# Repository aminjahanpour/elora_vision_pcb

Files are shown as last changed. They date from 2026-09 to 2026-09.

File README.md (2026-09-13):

# Elora Vision PCB

KiCad files for image_over_lora project PCB

## Goal
The most important goal for image_over_lora project is to keep the costs low.
So I've made it such that you could simply use already existing boards to set up and work with the porject [just as explained here](https://github.com/aminjahanpour/image_over_lora_android).
For doing that you'd need two boards: a black pill and an a LoRa module.

It could be that a PCB that integerates both of those two modules <b> would cost less</b>.

That is why I've started this project.

## Specs
### General
This is a compact 4-layer PBC powered only via its USB 2.0 connection (Type C plug).
In total, 6 LEDs are included to provide a decent elaboration on both USB and Radio data 
tx/rx processes and possible errors.
A 2-pin SW debug plug is provided for debugging and uploading the firmware.
Also, a USART plug is provided.
To lower the final cost, I used JLCPCB basic parts (rather than extended parts) where I could.
The LCSC part numbers for the parts are included in the BOM.
Use these part numbers to look up the exact components on the JLCPCB website.

### MCU
The board is centered around an STM32F411CEU6 chip.
It provides enough processing power for our Elora Vision firmware.

### LoRa
I chose RX1276 as for the LoRa module because this is perhaps the most common one in North America where I live.
The design targets 915 MHz abiding to the legal frequency bands in Canada.
I went with the IPEX antenna connection because it allows for more flexibility in antenna placement on the UAV.
The radio circuitry is based on the below sources:
- [Semtech reference design](https://www.semtech.com/products/wireless-rf/lora-connect/sx1276)
- [a design by Modtronix](https://modtronix.com/product/inair9b/)

[Also check out my question on StackExchange](https://electronics.stackexchange.com/questions/670470/circuitry-around-sma-for-a-lora-module-pcb-rx1276) regarding the radio circuitry. The given answer is pretty informative.

### Credits

- [A great guide for implementing USB-C in your KiCad projects](https://github.com/jenschr/USB-C-Connectors)
- I highly recommend taking [Phil's Lab PCB design courses](https://www.phils-lab.net/). It helped me a lot.

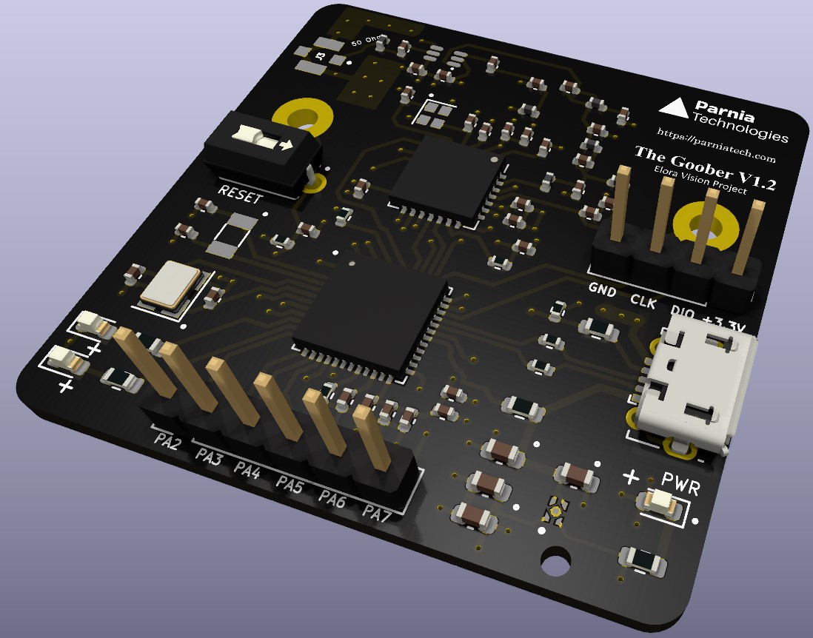
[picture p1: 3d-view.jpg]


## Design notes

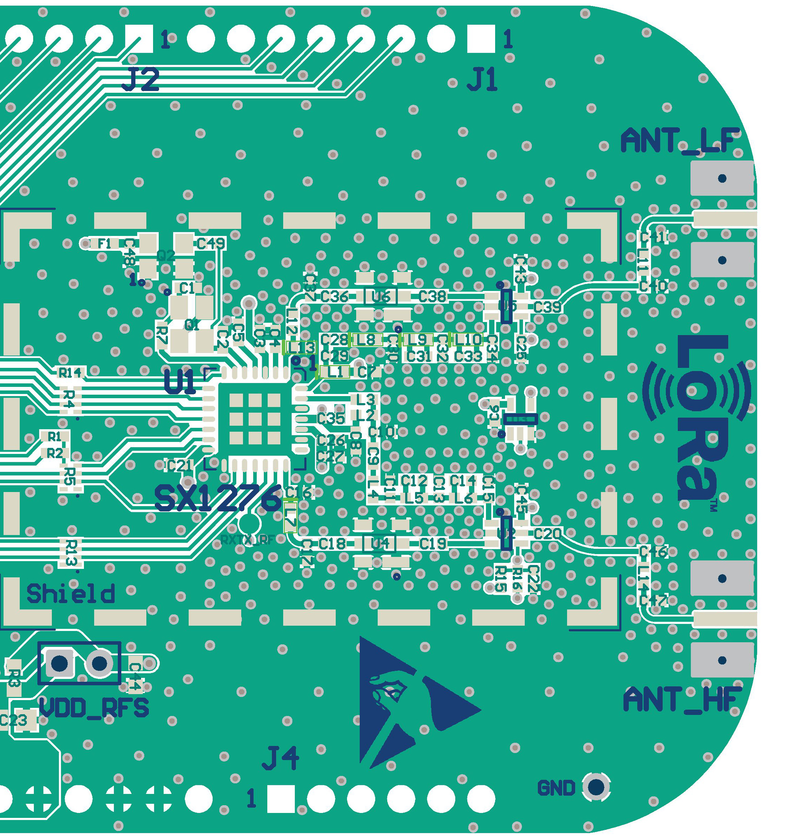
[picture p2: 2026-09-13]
docs/SX1276 Reference Designs/SX1276MB1LAS_e311v02a_prod_folder/SX1276MB1LAS_e311v02a_inductors LQG orientation.jpg

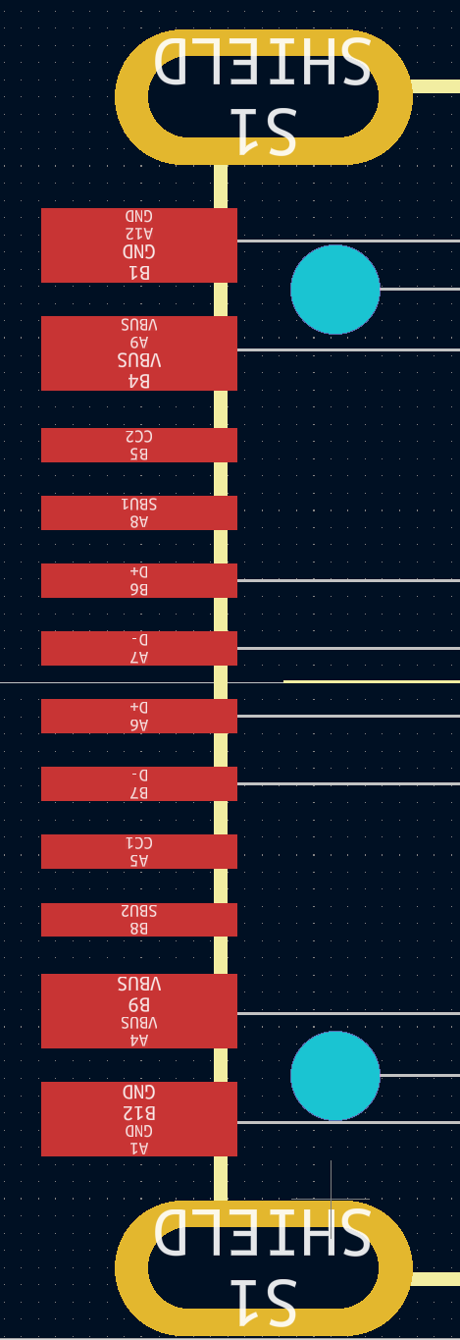
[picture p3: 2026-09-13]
image/usb_c.png

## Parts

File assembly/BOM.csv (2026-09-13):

Comment | Designator | Footprint | LCSC
SW_SPST_SKHLAAA010 | B2 | SKHLAAA010:SKHLAAA010
1uF | C11,C12 | Capacitor_SMD:C_0603_1608Metric
100nF | C14,C15 | Capacitor_SMD:C_0603_1608Metric
47pF | C16,C25,C26,C32,C37 | Capacitor_SMD:C_0402_1005Metric
100nF | C1,C3,C8,C9,C10,C18,C20,C21,C22,C36 | Capacitor_SMD:C_0402_1005Metric
10pF | C19,C38,C40,C43 | Capacitor_SMD:C_0402_1005Metric
10uF | C2 | Capacitor_SMD:C_0402_1005Metric
3.3pF | C24,C30 | Capacitor_SMD:C_0402_1005Metric
8.2pF | C29,C34 | Capacitor_SMD:C_0402_1005Metric
1.5pF | C31 | Capacitor_SMD:C_0402_1005Metric
10nF | C33 | Capacitor_SMD:C_0402_1005Metric
22pF | C35 | Capacitor_SMD:C_0402_1005Metric
2.2pF | C39,C41 | Capacitor_SMD:C_0402_1005Metric
1nF | C4,C23 | Capacitor_SMD:C_0402_1005Metric
2.2uF | C6 | Capacitor_SMD:C_0402_1005Metric
4.7uF | C7 | Capacitor_SMD:C_0402_1005Metric
LED_GREEN_PWR | D1 | LED_SMD:LED_0603_1608Metric
LED_GREEN_1 | D2 | LED_SMD:LED_0603_1608Metric
LED_YELLOW_1 | D3 | LED_SMD:LED_0603_1608Metric
MountingHole_Pad | H3,H4 | MountingHole:MountingHole_2.2mm_M2_Pad
USB_B_Micro | J1 | Connector_USB:USB_Micro-B_Molex-105017-0001
Conn_01x04_Male | J2 | Connector_PinHeader_2.54mm:PinHeader_1x04_P2.54mm_Vertical
IPEX_73412-0114 | J3 | MOLEX_73412-0114
Conn_01x06_Male | J4 | Connector_PinHeader_2.54mm:PinHeader_1x06_P2.54mm_Vertical
0R | L1 | Inductor_SMD:L_0402_1005Metric
10nH Wire | L2 | Inductor_SMD:L_0402_1005Metric
4.7nH Wire | L4 | Inductor_SMD:L_0402_1005Metric
5.6nH Wire | L5 | Inductor_SMD:L_0402_1005Metric
33nH | L6 | Inductor_SMD:L_0402_1005Metric
2.2nH Wire | L7 | Inductor_SMD:L_0402_1005Metric
32MHz | Q1 | Crystal:Crystal_SMD_2016-4Pin_2.0x1.6mm
560 | R1,R8,R9,R10,R13 | Resistor_SMD:R_0603_1608Metric
100k | R15 | Resistor_SMD:R_0402_1005Metric
10K | R2,R3,R6 | Resistor_SMD:R_0402_1005Metric
22 | R4,R5 | Resistor_SMD:R_0402_1005Metric
1k | R7 | Resistor_SMD:R_0402_1005Metric
STM32F411CEU6 | U1 | Package_DFN_QFN:QFN-48-1EP_7x7mm_P0.5mm_EP5.6x5.6mm
AP7340-12FS4-7 | U2 | AP7340D:VREG_AP7340D-25FS4-7
PE4259 | U5 | PE4259:SOT65P215X110-6N
SX1276 | U6 | Package_DFN_QFN:QFN-28-1EP_6x6mm_P0.65mm_EP4.8x4.8mm
12 MHz (C9002) | Y4 | Crystal:Crystal_SMD_3225-4Pin_3.2x2.5mm
32.768 kHz | Y5 | Crystal:Crystal_SMD_3215-2Pin_3.2x1.5mm

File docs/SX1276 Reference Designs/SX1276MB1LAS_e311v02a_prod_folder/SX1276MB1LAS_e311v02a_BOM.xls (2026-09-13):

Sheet: SX1276MB1LAS - BOM
 |  |  | SX1276MB1LAS - BOM |  |  | BOM # V1a
 |  |  |  |  |  | SCH # e311V02a
 |  |  | 2015-11-09 | EMr | Version e311V02a - 915MHz on RF_HF and 433MHz on RF_LF | PCB # e311V02a
RefDes | MPN | Geom | Value | Qty | Description | Manufacturer
IC
U1 | SX1276IMLTRT | TQFN-28 6x6mm | SX1276 | 1 | 137MHz to 1020MHz Low Power Long Range Transceiver | Semtech
U2 | PE4259 | SC-70 | - | 1 | PE4259 - 10MHz to 3GHz SPDT RF Switch | Peregrine Semi
U3 | NC7SZ04P5X | SC-70-5 | - | 1 | NC7SZ04 TinyLogic UHS Inverter | Fairchild Semi
U4 | CRCW06030000Z0EA | 0603 | 0R | 1 | Thick Film Resistor ±5%, 1/10W (No SAW filter populated) | Vishay/Dale
U5 | PE4259 | SC-70 | - | 1 | PE4259 - 10MHz to 3GHz SPDT RF Switch | Peregrine Semi
U6 | CRCW06030000Z0EA | 0603 | 0R | 1 | Thick Film Resistor ±5%, 1/10W (No SAW filter populated) | Vishay/Dale
Resistors
R1 | CRCW04020000Z0ED | 0402 | 0R | 1 | Thick Film Resistor ±5%, 1/16W | Vishay/Dale
R2 | CRCW04020000Z0ED | 0402 | 0R | 1 | Thick Film Resistor ±5%, 1/16W | Vishay/Dale
R3 | CRCW06030000Z0EA | 0603 | 0R | 1 | Thick Film Resistor ±5%, 1/10W | Vishay/Dale
R4 | EXB-N8V101JX | EXB28V | 100R | 1 | SMD Resistor Array Resistors (4x), ±5%, 31mW | Panasonic - ECG
R5 | EXB-N8V101JX | EXB28V | 100R | 1 | SMD Resistor Array Resistors (4x), ±5%, 31mW | Panasonic - ECG
R6 | CRCW06030000Z0EA | 0603 | 0R | 1 | Thick Film Resistor ±5%, 1/10W | Vishay/Dale
R7 | CRCW04020000Z0ED | 0402 | 0R | 1 | Thick Film Resistor ±5%, 1/16W | Vishay/Dale
R10 | CRCW04021K00JNED | 0402 | 1k | 1 | Thick Film Resistor ±5%, 1/16W | Vishay/Dale
R13 | EXB-N8V101JX | EXB28V | 100R | 1 | SMD Resistor Array Resistors (4x), ±5%, 31mW | Panasonic - ECG
R14 | CRCW0402100RJNED | 0402 | 100R | 1 | Thick Film Resistor ±5%, 1/16W | Vishay/Dale
R16 | CRCW0402100RJNED | 0402 | 100R | 1 | Thick Film Resistor ±5%, 1/16W | Vishay/Dale
Capacitors
C1 | GRM1555C1H150JA01D | 0402 | 15pF | 1 | Multilayer ceramic capacitors C0G ±5%, 50V for Rakon Crystal (18pF for NDK) | Murata
C2 | GRM1555C1H150JA01D | 0402 | 15pF | 1 | Multilayer ceramic capacitors C0G ±5%, 50V for Rakon Crystal (18pF for NDK) | Murata
C3 | GRM155R71C104KA88D | 0402 | 100nF | 1 | Multilayer ceramic capacitors X7R ±10%, 16V | Murata
C4 | GRM155R71C104KA88D | 0402 | 100nF | 1 | Multilayer ceramic capacitors X7R ±10%, 16V | Murata
C5 | GRM155R71C104KA88D | 0402 | 100nF | 1 | Multilayer ceramic capacitors X7R ±10%, 16V | Murata
C6 | GRM155R71C104KA88D | 0402 | 100nF | 1 | Multilayer ceramic capacitors X7R ±10%, 16V | Murata
C7 | GRM1555C1H470JZ01D | 0402 | 47pF | 1 | Multilayer ceramic capacitors C0G ±5%, 50V | Murata
C8 | GRM1555C1H470JZ01D | 0402 | 47pF | 1 | Multilayer ceramic capacitors C0G ±5%, 50V | Murata
C9 | GRM1555C1H220JZ01D | 0402 | 22pF | 1 | Multilayer ceramic capacitors C0G ±5%, 50V | Murata
C10 | GRM1555C1H8R2CZ01D | 0402 | 8.2pF | 1 | Multilayer ceramic capacitors C0G ±5%, 50V | Murata
C11 | GRM1555C1H6R8CA01D | 0402 | 6.8pF | 1 | Multilayer ceramic capacitors C0G ±0.25pF, 50V | Murata
C13 | GRM1555C1H3R3CZ01D | 0402 | 3.3pF | 1 | Multilayer ceramic capacitors C0G ±0.25pF, 50V | Murata
C17 | GRM1555C1H3R3CZ01D | 0402 | 3.3pF | 1 | Multilayer ceramic capacitors C0G ±0.25pF, 50V | Murata
C18 | GRM1555C1H470JZ01D | 0402 | 47pF | 1 | Multilayer ceramic capacitors C0G ±5%, 50V | Murata
C19 | GRM1555C1H470JZ01D | 0402 | 47pF | 1 | Multilayer ceramic capacitors C0G ±5%, 50V | Murata
C20 | GRM1555C1H470JZ01D | 0402 | 47pF | 1 | Multilayer ceramic capacitors C0G ±5%, 50V | Murata
C21 | GRM155R71C104KA88D | 0402 | 100nF | 1 | Multilayer ceramic capacitors X7R ±10%, 16V | Murata
C22 | GRM155R71H102JA01D | 0402 | 1nF | 1 | Multilayer ceramic capacitors X7R ±5%, 50V | Murata
C23 | GRM21BR60J226ME39L | 0805 | 22uF | 1 | Multilayer ceramic capacitors X5R ±20%, 6.3V | Murata
C24 | GRM188R61A105KA61D | 0603 | 1uF | 1 | Multilayer ceramic capacitors X5R ±10%, 10V | Murata
C25 | GRM155R71H102JA01D | 0402 | 1nF | 1 | Multilayer ceramic capacitors X7R ±5%, 50V | Murata
C26 | GRM1555C1H470JZ01D | 0402 | 47pF | 1 | Multilayer ceramic capacitors C0G ±5%, 50V | Murata
C27 | GRM155R71C104KA88D | 0402 | 100nF | 1 | Multilayer ceramic capacitors X7R ±10%, 16V | Murata
C28 | LQG15HS15NJ02D | 0402 | 15nH | 1 | Multilayer Inductor ±5% | Murata
C29 | GRM1555C1H4R7CA01D | 0402 | 4.7pF | 1 | Multilayer ceramic capacitors C0G ±0.25pF, 50V | Murata
C30 | GRM1555C1H6R8CA01D | 0402 | 6.8pF | 1 | Multilayer ceramic capacitors C0G ±0.25pF, 50V | Murata
C31 | GRM1555C1H2R7CZ01D | 0402 | 2.7pF | 1 | Multilayer ceramic capacitors C0G ±0.25pF, 50V | Murata
C32 | GRM1555C1H6R8CA01D | 0402 | 6.8pF | 1 | Multilayer ceramic capacitors C0G ±0.25pF, 50V | Murata
C35 | GRM155R71E103KA01D | 0402 | 10nF | 1 | Multilayer ceramic capacitors X7R ±10%, 25V | Murata
C36 | GRM1555C1H470JZ01D | 0402 | 47pF | 1 | Multilayer ceramic capacitors C0G ±5%, 50V | Murata
C38 | GRM1555C1H470JZ01D | 0402 | 47pF | 1 | Multilayer ceramic capacitors C0G ±5%, 50V | Murata
C39 | GRM1555C1H470JZ01D | 0402 | 47pF | 1 | Multilayer ceramic capacitors C0G ±5%, 50V | Murata
C43 | GRM155R71H102JA01D | 0402 | 1nF | 1 | Multilayer ceramic capacitors X7R ±5%, 50V | Murata
C44 | GRM188R61A105KA61D | 0603 | 1uF | 1 | Multilayer ceramic capacitors X5R ±10%, 10V | Murata
C45 | GRM155R71H102JA01D | 0402 | 1nF | 1 | Multilayer ceramic capacitors X7R ±5%, 50V | Murata
C50 | GRM188R61A105KA61D | 0603 | 1uF | 1 | Multilayer ceramic capacitors X5R ±10%, 10V | Murata
Inductors & Ferrites
L1 | LQG15HS82NJ02D | 0402 | 82nH | 1 | Multilayer Inductor ±5% | Murata
L2 | LQW15AN33NJ00D | 0402 | 33nH | 1 | Wirewound Inductor ±5% | Murata
L3 | LQW15AN1N5C00D | 0402 | 1.5nH | 1 | Wirewound Inductor ±0.2nH | Murata
L4 | LQW15AN5N6C10D | 0402 | 5.6nH | 1 | Wirewound Inductor ±0.2nH | Murata
L5 | LQW15AN5N6C10D | 0402 | 5.6nH | 1 | Wirewound Inductor ±0.2nH | Murata
L6 | CRCW04020000Z0ED | 0402 | 0R | 1 | Thick Film Resistor ±5%, 1/16W | Vishay/Dale
L7 | LQG15HS10NJ02D | 0402 | 10nH | 1 | Multilayer Inductor ±5% | Murata
L8 | CRCW04020000Z0ED | 0402 | 0R | 1 | Thick Film Resistor ±5%, 1/16W | Vishay/Dale
L9 | LQG15HS12NJ02D | 0402 | 12nH | 1 | Multilayer Inductor ±5% | Murata
L10 | CRCW04020000Z0ED | 0402 | 0R | 1 | Thick Film Resistor ±5%, 1/16W | Vishay/Dale
L11 | CRCW04020000Z0ED | 0402 | 0R | 1 | Thick Film Resistor ±5%, 1/16W | Vishay/Dale
L12 | GRM1555C1H4R7CZ01D | 0402 | 4.7pF | 1 | Multilayer ceramic capacitors C0G ±0.25pF, 50V | Murata
L13 | LQG15HS18NJ02D | 0402 | 18nH | 1 | Multilayer Inductor ±5% | Murata
L14 | CRCW04020000Z0ED | 0402 | 0R | 1 | Thick Film Resistor ±5%, 1/16W | Vishay/Dale
Crystal (or other referenced vendors)
Q1 | FTR5092-A2 | QESM07 3.2x2.5mm | 32.000MHz | 1 | Crystal unit Rakon; Tol. ±10ppm, Cload=10pF, G-Senstivity=2ppb/G max (populated) | Rakon
or | FTR5123-A0 | QESM09 2.0x1.6mm | 32.000MHz | - | Crystal unit Rakon; Tol. ±10ppm, Cload=10pF, G-Senstivity=2ppb/G max (recommended for new design) | Rakon
Q1 | EXS00A-CS00131 | NX2520SA 2.5x2.0mm | 32.000MHz | - | Crystal unit NDK; Tol. ±10ppm, Cload=10pF, G-Senstivity=2ppb/G max | NDK
or | EXS00A-CS06465 | NX2016SA 2.0x1.6mm | 32.000MHz | - | Crystal unit NDK; Tol. ±10ppm, Cload=10pF, G-Senstivity=2ppb/G max (recommended for new design) | NDK
Q1 | S0197-X-002-3 | QESM07 3.2x2.5mm | 32.000MHz | - | Crystal unit Taitien; Tol. ±10ppm, Cload=10pF, G-Senstivity=2ppb/G max | Taitien
Connectors and others (or P/N equivalent)
ANT_HF | 142-0711-821 | SMA End Launch | 50 Ohms | 1 | SMA End launch jack receptacle for PCB mount | Emerson Network Power
ANT_LF | 142-0711-821 | SMA End Launch | 50 Ohms | 1 | SMA End launch jack receptacle for PCB mount | Emerson Network Power
J1 | 68000-108HLF | Header 1x8 | 8 pins | 1 | 8 Pins - Through hole single row male connector, Bottom side | FCI
J2 | 68000-110HLF | Header 1x10 | 10 pins | 1 | 10 Pins - Through hole single row male connector, Bottom side | FCI
J3 | 68000-108HLF | Header 1x8 | 8 pins | 1 | 8 Pins - Through hole single row male connector, Bottom side | FCI
J4 | 68000-106HLF | Header 1x6 | 6 pins | 1 | 6 Pins - Through hole single row male connector, Bottom side | FCI
Additional or optional components
- | BMIS-205-F | Shield | - | 0 | Standard Surface Mount Shield in two parts with BMIS-205-C cover | Laird Technologies

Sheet: Release
 |  | SX1276MB1LAS - BOM |  |  |  | BOM # V1a
 |  |  |  |  |  | SCH # e311V02a
 |  | 2015-11-09 | EMr | Version e311V02a |  | PCB # e311V02a
Release histroy
Version | Change notes |  |  |  | By
pcb_e311V02a | BOM for SX1276MB1LAS V1a |  |  |  | EMr
 | Added Pull-up/down resistors on RXTX_EXT signal |  |  |  | EMr
 | Modified BOM to have the correct ouput power +17dBm @915MHz and Harmonics |  |  |  | EMr
 | L3, C11 and removed C12 |  |  |  | EMr
 | Modified BOM to have the correct ouput power +14dBm @433MHz |  |  |  | EMr
 | Modified value for references: L1, C28, C29, L8, C30, C32, L10 & C34=NC
 | Modified value for RxTX control on R10=1k; R16=100R |  |  |  | EMr
 | Added two new ref for 32.0MHz crystal |  |  |  | EMr

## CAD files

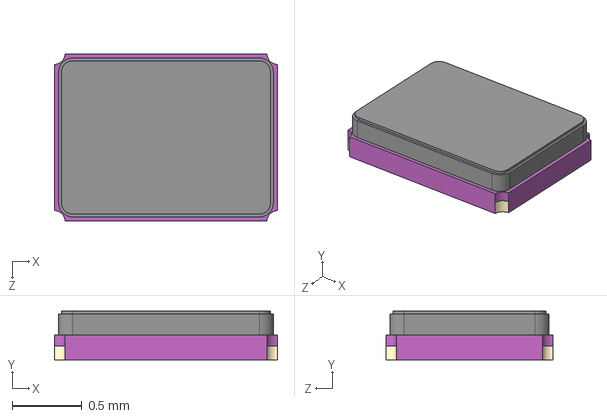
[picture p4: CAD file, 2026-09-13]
added_symbols/NX1612SA-32.000MHZ-CHP-CIS-3/NX1612SA-32.000MHZ-CHP-CIS-3.step
1.60 x 0.35 x 1.20 mm

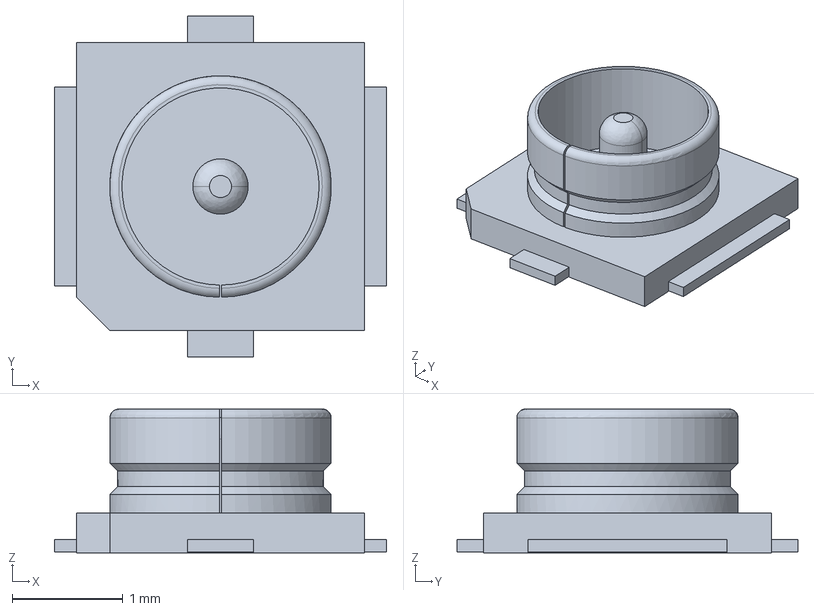
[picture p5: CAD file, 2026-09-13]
added_symbols/ipex_molex_73412-0114/1676492.stp
3.00 x 3.08 x 1.30 mm

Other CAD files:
added_symbols/ipex_molex_73412-0114/73412-0114.step

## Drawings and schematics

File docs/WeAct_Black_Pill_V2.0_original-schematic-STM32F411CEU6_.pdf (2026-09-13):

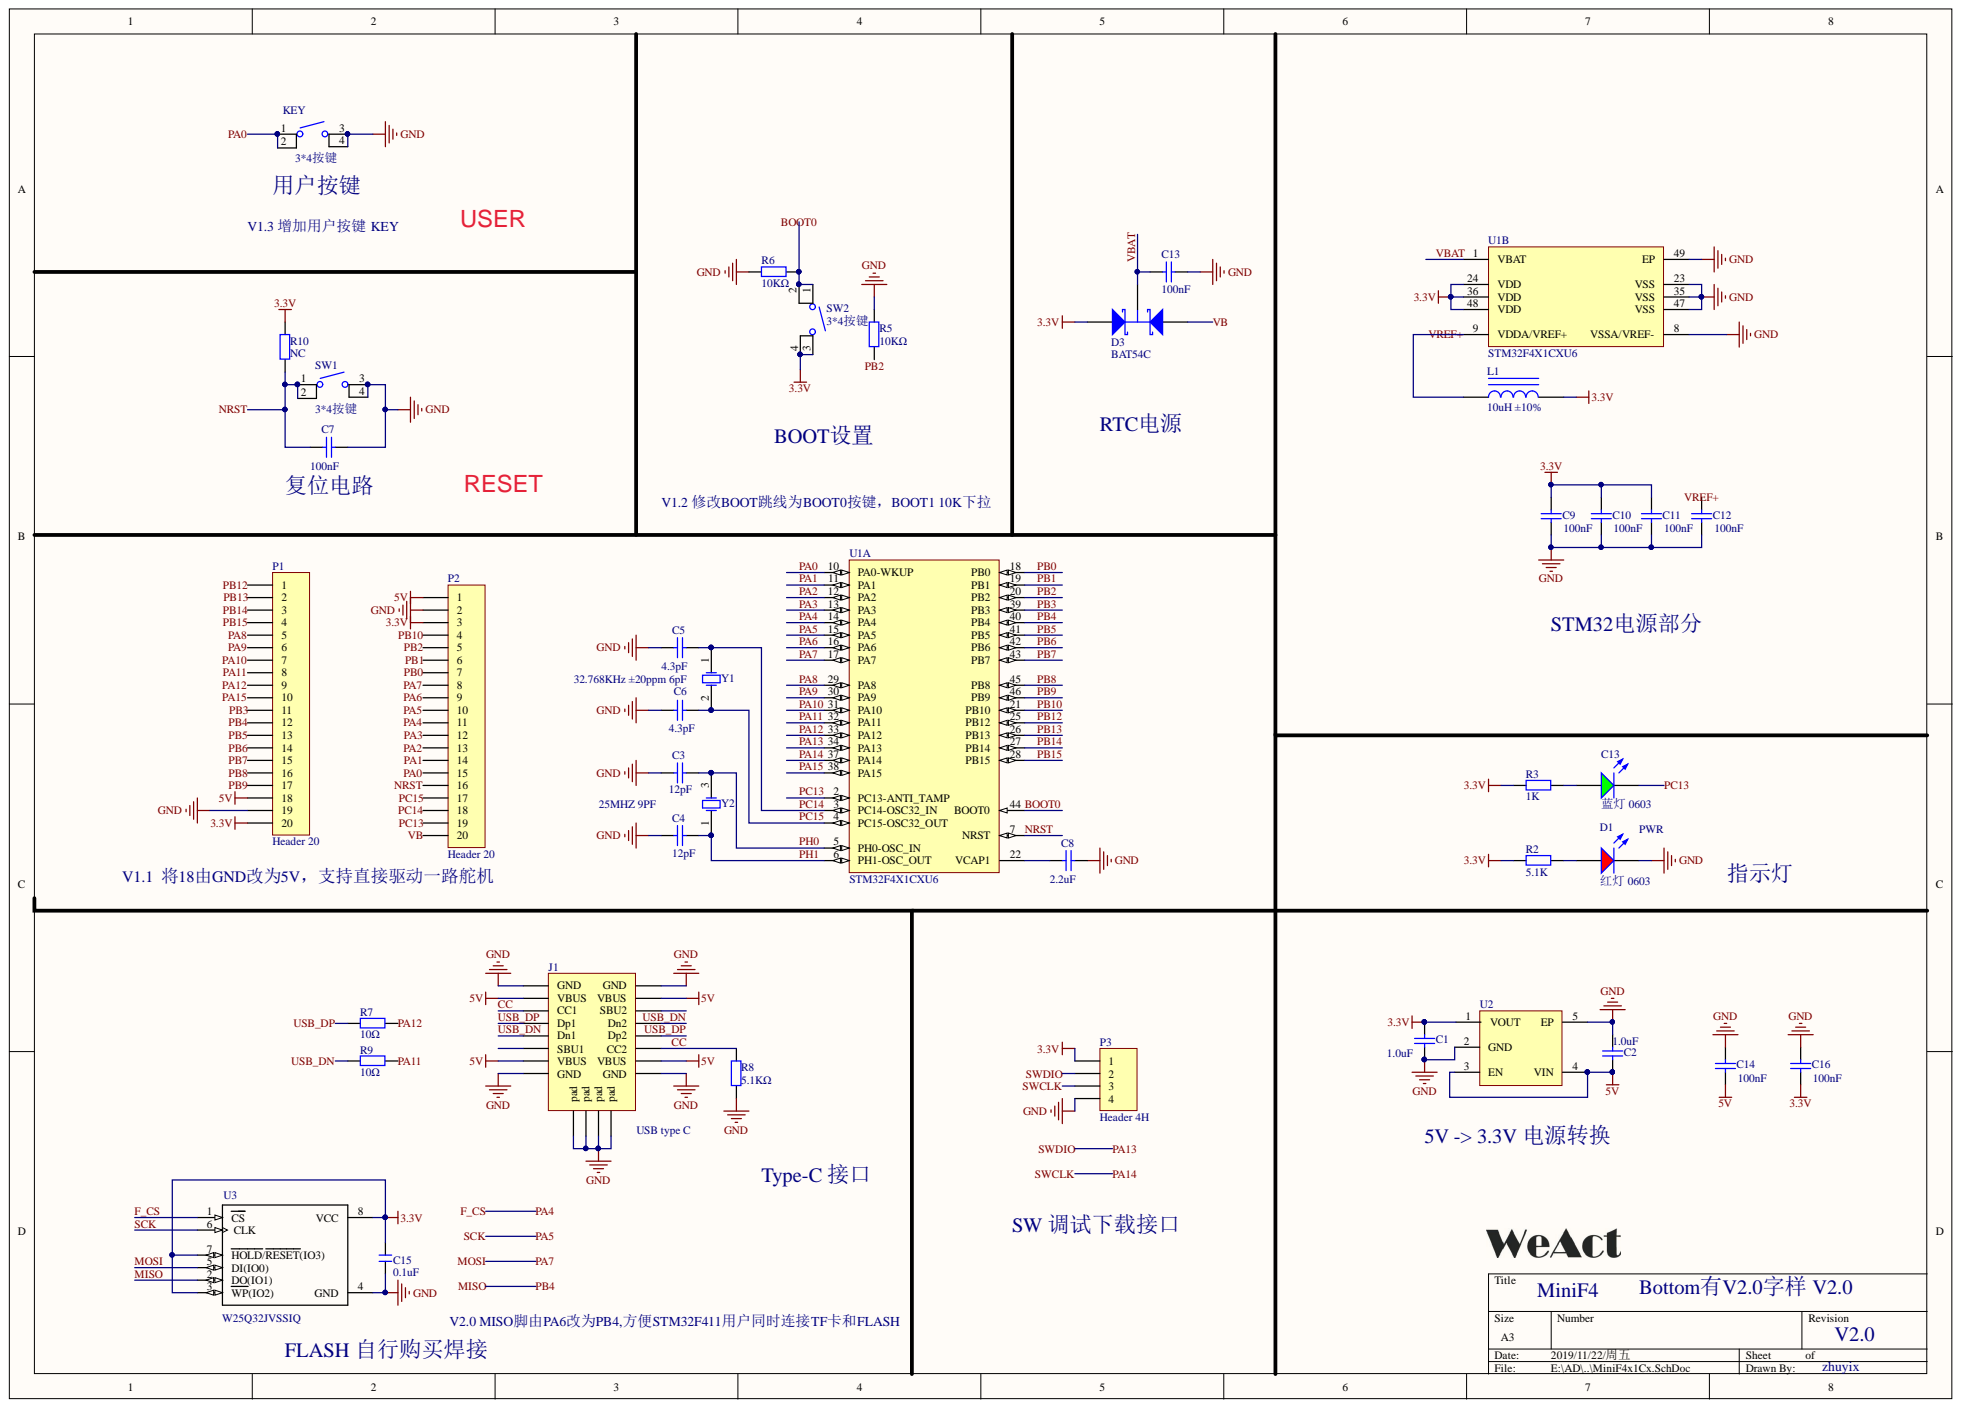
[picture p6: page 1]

PH0-OSC_IN 5

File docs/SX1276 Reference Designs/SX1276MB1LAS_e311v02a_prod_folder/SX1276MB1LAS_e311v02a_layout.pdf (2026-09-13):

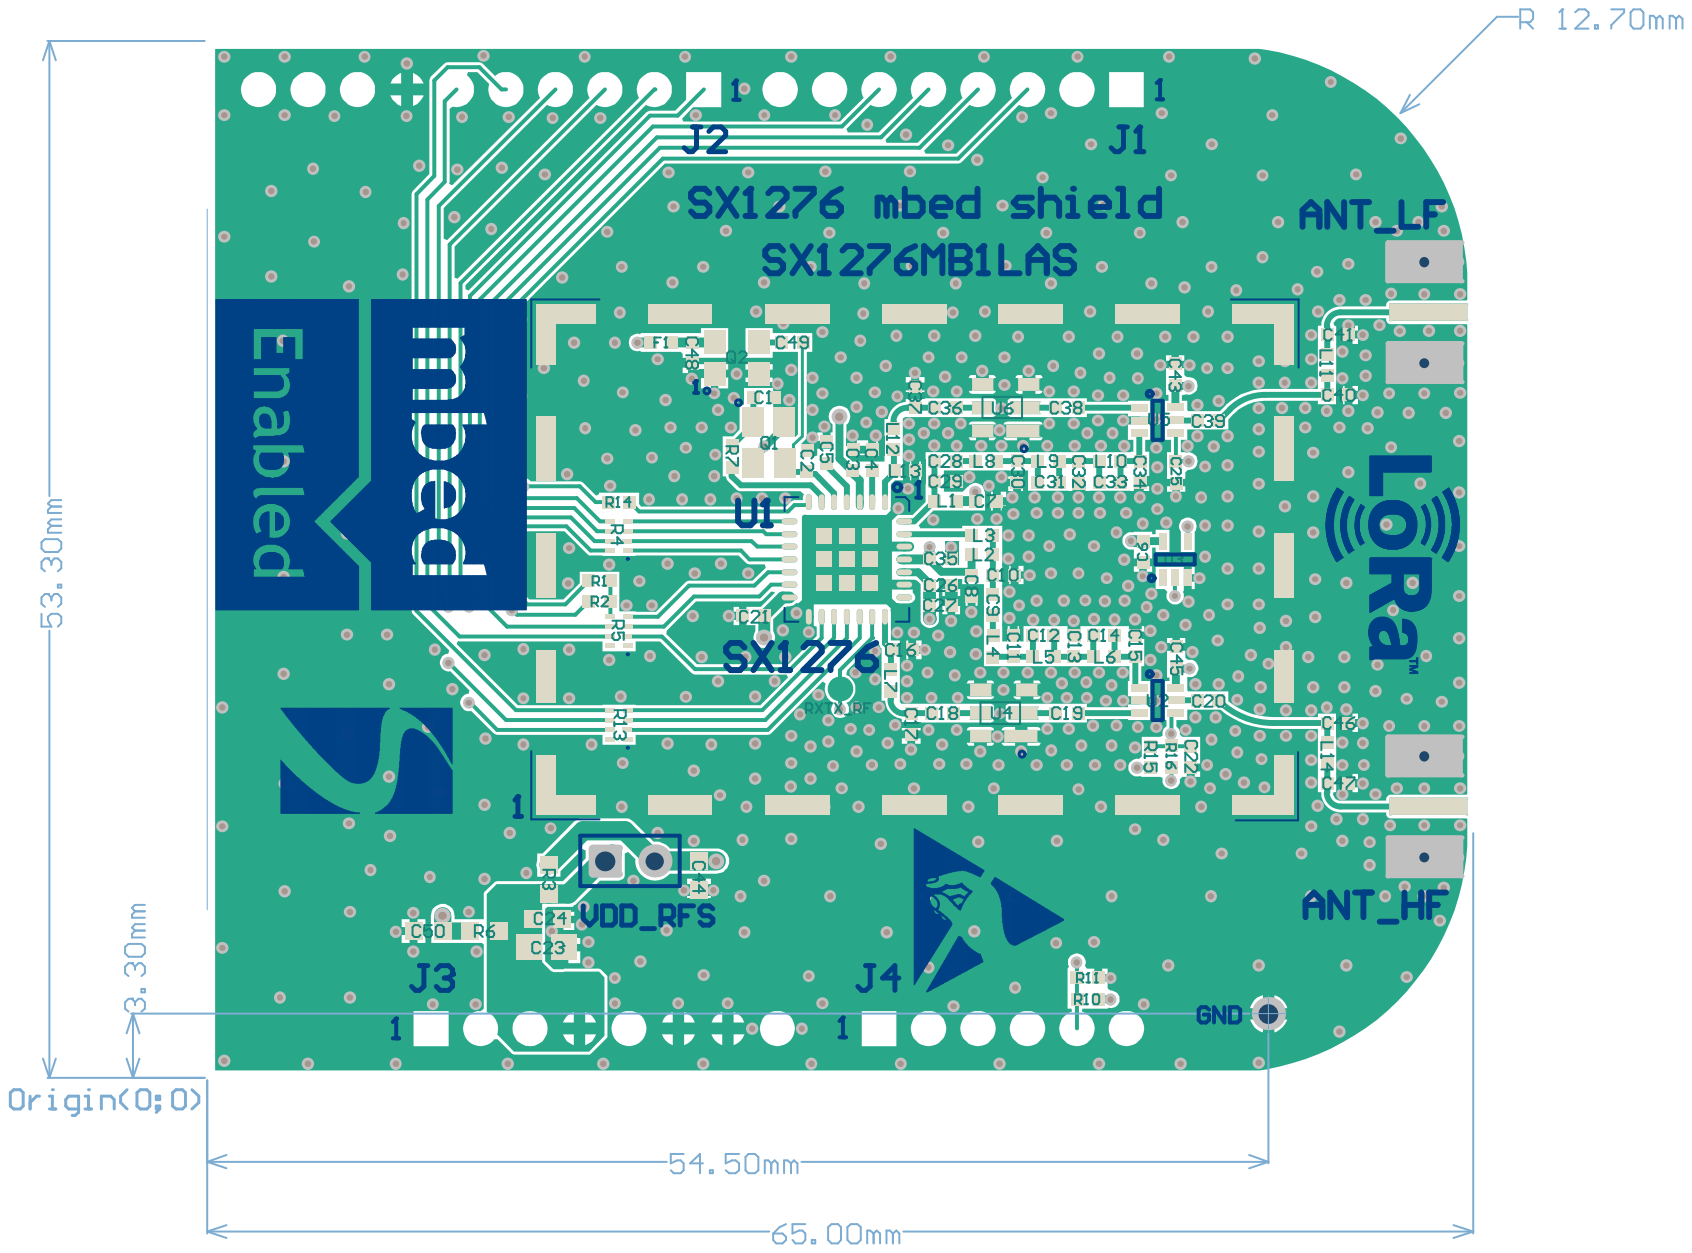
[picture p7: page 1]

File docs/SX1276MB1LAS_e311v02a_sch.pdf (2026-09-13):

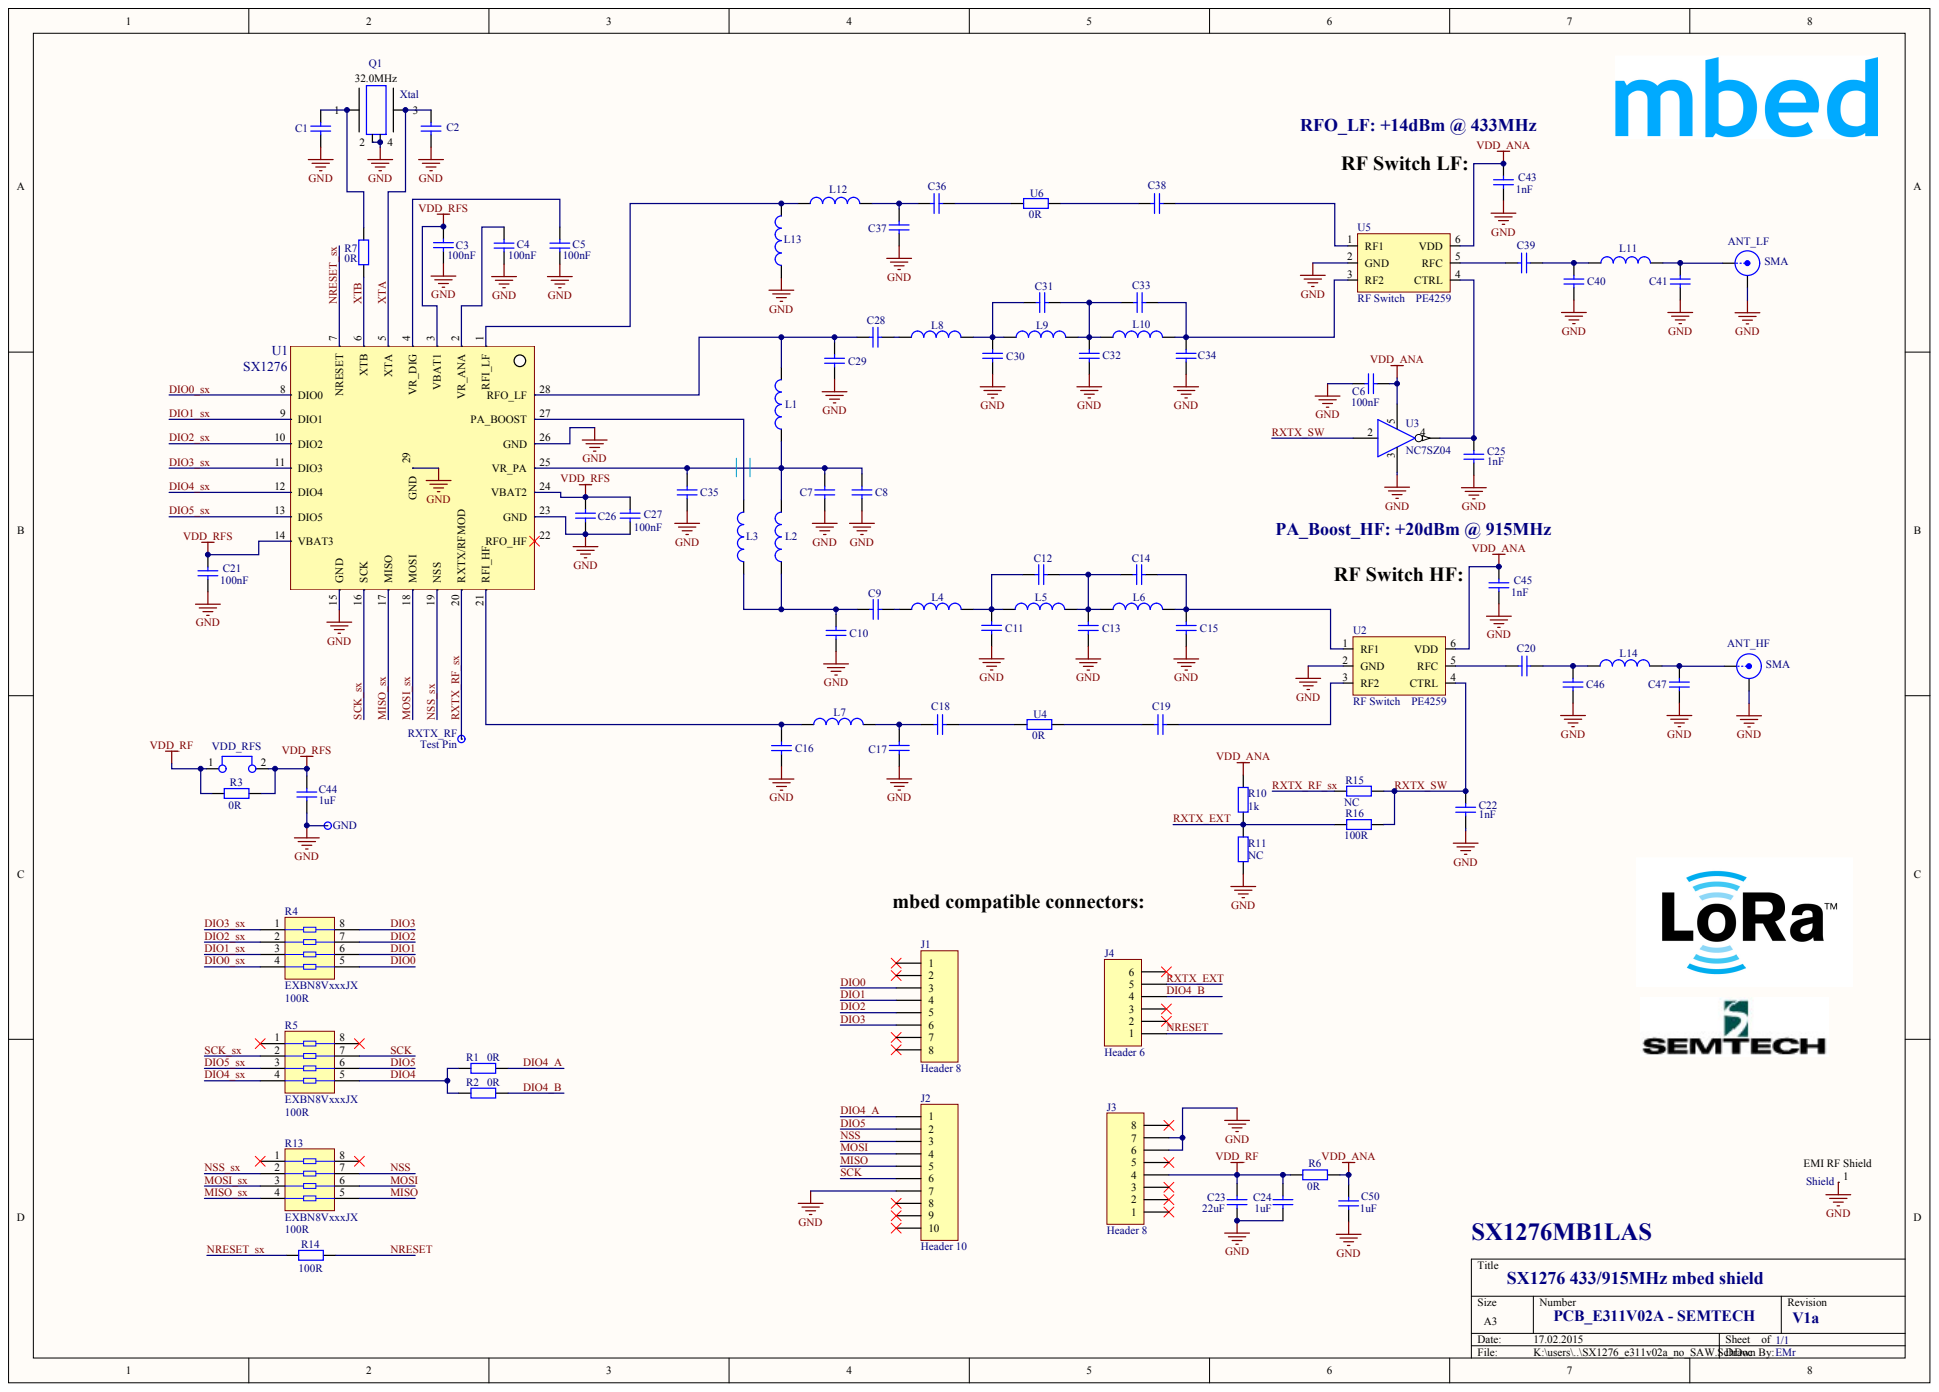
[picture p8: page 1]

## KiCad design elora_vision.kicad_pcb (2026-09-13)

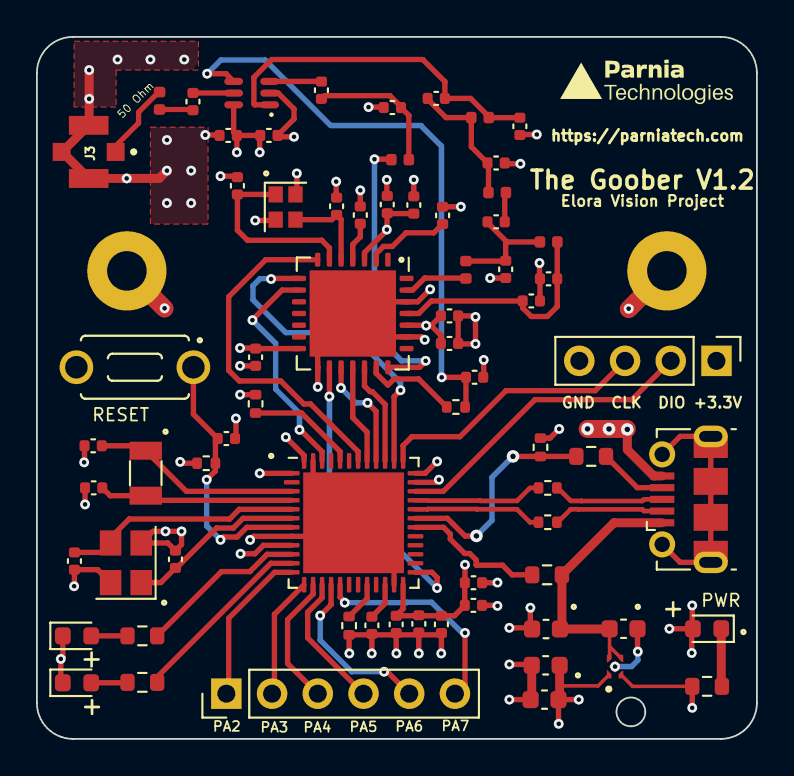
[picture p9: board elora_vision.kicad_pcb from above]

Board: 4 copper layers, 40.0 x 39.0 mm, 72 parts (0 on the bottom side), 57 nets.

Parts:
B2: SW_SPST_SKHLAAA010; SKHLAAA010
C1, C3, C8, C9, C10, C18, C20, C21, C22, C36: 100nF; C_0402_1005Metric
C2: 10uF; C_0402_1005Metric
C4, C23: 1nF; C_0402_1005Metric
C6: 2.2uF; C_0402_1005Metric
C7: 4.7uF; C_0402_1005Metric
C11, C12: 1uF; C_0603_1608Metric
C14, C15: 100nF; C_0603_1608Metric
C16, C25, C26, C32, C37: 47pF; C_0402_1005Metric
C19, C38, C40, C43: 10pF; C_0402_1005Metric
C24, C30: 3.3pF; C_0402_1005Metric
C29, C34: 8.2pF; C_0402_1005Metric
C31: 1.5pF; C_0402_1005Metric
C33: 10nF; C_0402_1005Metric
C35: 22pF; C_0402_1005Metric
C39, C41: 2.2pF; C_0402_1005Metric
D1: LED_GREEN_PWR; LED_0603_1608Metric
D2: LED_GREEN_1; LED_0603_1608Metric
D3: LED_YELLOW_1; LED_0603_1608Metric
H3, H4: MountingHole_Pad; MountingHole_2.2mm_M2_Pad
J1: USB_B_Micro; USB_Micro-B_Molex-105017-0001
J2: Conn_01x04_Male; PinHeader_1x04_P2.54mm_Vertical
J3: IPEX_73412-0114; MOLEX_73412-0114
J4: Conn_01x06_Male; PinHeader_1x06_P2.54mm_Vertical
L1: 0R; L_0402_1005Metric
L2: 10nH Wire; L_0402_1005Metric
L4: 4.7nH Wire; L_0402_1005Metric
L5: 5.6nH Wire; L_0402_1005Metric
L6: 33nH; L_0402_1005Metric
L7: 2.2nH Wire; L_0402_1005Metric
Q1: 32MHz; Crystal_SMD_2016-4Pin_2.0x1.6mm
R1, R8, R9, R10, R13: 560; R_0603_1608Metric
R2, R3, R6: 10K; R_0402_1005Metric
R4, R5: 22; R_0402_1005Metric
R7: 1k; R_0402_1005Metric
R15: 100k; R_0402_1005Metric
U1: STM32F411CEU6; QFN-48-1EP_7x7mm_P0.5mm_EP5.6x5.6mm
U2: AP7340-12FS4-7; VREG_AP7340D-25FS4-7
U5: PE4259; SOT65P215X110-6N
U6: SX1276; QFN-28-1EP_6x6mm_P0.65mm_EP4.8x4.8mm
Y4: 12 MHz (C9002); Crystal_SMD_3225-4Pin_3.2x2.5mm
Y5: 32.768 kHz; Crystal_SMD_3215-2Pin_3.2x1.5mm

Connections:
+3.3V: C2.1, C3.2, C4.1, C7.2, C8.2, C9.2, C10.1, C12.2, C15.1, C16.2, C18.2, C22.1, C36.1, C37.1, D1.2 (A), J2.1, R3.2, R15.1, U1.1 (VBAT), U1.9 (VDDA), U1.24 (VDD), U1.36 (VDD), U1.48 (VDD), U2.1 (VOUT), U5.6 (VDD), U6.3 (VBAT_ANA), U6.14 (VBAT_DIG), U6.24 (VBAT_RF)
+5V: C11.2, C14.1, J1.1 (VBUS), R13.2, U2.3 (EN), U2.4 (VIN)
/MCU/D+: J1.3 (D+), R5.2
/MCU/D-: J1.2 (D-), R4.2
BOOT0: R2.1, U1.44 (BOOT0)
GND: B2.2, C1.1, C2.2, C3.1, C4.2, C6.1, C7.1, C8.1, C9.1, C10.2, C12.1, C14.2, C15.2, C16.1, C18.1, C19.2, C20.1, C21.1, C22.2, C23.2, C24.2, C29.2, C30.2, C32.2, C33.2, C34.2, C36.2, C37.2, C38.2, C39.2, C40.2, C41.2, C43.2, D2.1 (K), D3.1 (K), H3.1, H4.1, J1.5 (GND), J2.4, J3.2, J3.3, J3.4, Q1.2, Q1.4, R2.2, R6.1, R8.2, U1.8 (VSSA), U1.23 (VSS), U1.35 (VSS), U1.47 (VSS), U1.49 (VSS), U2.2 (GND), U5.2 (GND), U6.15 (GND), U6.23 (GND), U6.26 (GND), U6.29 (GND), Y4.2, Y4.4
HSE_IN: C40.1, U1.5 (PH0), Y4.3
HSE_OUT: C38.1, U1.6 (PH1), Y4.1
LED_GREEN: R9.2, U1.10 (PA0)
LED_YELLOW_1: R10.2, U1.11 (PA1)
LORA_DIO0: U1.38 (PA15), U6.8 (DIO0)
LORA_DIO1: U1.46 (PB9), U6.9 (DIO1)
LORA_MISO: U1.40 (PB4), U6.17 (MISO)
LORA_MOSI: U1.41 (PB5), U6.18 (MOSI)
LORA_NSS: U1.39 (PB3), U6.19 (NSS)
LORA_RESET: U1.42 (PB6), U6.7 (NRESET)
LORA_SCK: U1.25 (PB12), U6.16 (SCK)
LSE_IN: C39.1, U1.3 (PC14), Y5.1
LSE_OUT: C41.1, U1.4 (PC15), Y5.2
NRST: B2.1, C1.2, R3.1, U1.7 (NRST)
unnamed: C24.1, C25.1, L2.2
unnamed: C26.1, L1.1
unnamed: C29.1, C31.1, L4.1, L5.2
unnamed: C34.1, C35.1, L6.2, L7.2
unnamed: C35.2, L5.1
unnamed: D1.1 (K), R8.1
unnamed: D2.2 (A), R9.1
unnamed: D3.2 (A), R10.1
unnamed: J1.4 (ID), R1.2
unnamed: J3.1, L1.2
unnamed: C6.2, U1.22 (VCAP1)
unnamed: C11.1, U2.5 (EXP)
unnamed: C23.1, R7.2, U5.4 (CTRL)
unnamed: C30.1, C31.2, L4.2, U5.1 (RF1)
unnamed: C25.2, U5.3 (RF2)
unnamed: C26.2, U5.5 (RFC)
unnamed: L7.1, U6.27 (PA_BOOST)
unnamed: L2.1, U6.21 (RFI_HF)
unnamed: R7.1, U6.20 (RXTX/RFMOD)
unnamed: C20.2, U6.2 (VR_ANA)
unnamed: C21.2, U6.4 (VR_DIG)
unnamed: C32.1, C33.1, L6.1, U6.25 (VR_PA)
unnamed: C43.1, Q1.3, U6.5 (XTA)
unnamed: C19.1, Q1.1, U6.6 (XTB)
PA2: J4.1, U1.12 (PA2)
PA3: J4.2, U1.13 (PA3)
PA4: J4.3, U1.14 (PA4)
PA5: J4.4, U1.15 (PA5)
PA6: J4.5, U1.16 (PA6)
PA7: J4.6, U1.17 (PA7)
PA9_VBUS: R13.1, U1.30 (PA9)
PA10: R1.1, R15.2, U1.31 (PA10)
PA13: J2.2, U1.34 (PA13)
PA14: J2.3, U1.37 (PA14)
PB2: R6.2, U1.20 (PB2)
USB_D+: R5.1, U1.33 (PA12)
USB_D-: R4.1, U1.32 (PA11)
